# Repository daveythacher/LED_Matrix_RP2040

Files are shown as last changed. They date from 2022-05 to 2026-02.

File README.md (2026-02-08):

# LED_Matrix_RP2040
Hardware module for abstracting LED matrix interface. Raw data is sent over an IO bus which is then replayed to the LED matrix repeatedly. Application logic is responsible for producing raw data and generating synchronization signal.

## Status
This code base is a work in progress. See [this](https://github.com/daveythacher/LED_Matrix_RP2040/blob/main/LED_Matrix/README.md#status) for more details.

This code basis will likely be abandoned due to integrity issues. Most LED Matrix libraries have issues with integrity. I have been on an adventure trying to improve the quality of LED Matrix displays, which is quite poor in my opinion. Only some of my findings have been documented and at some point I will just have to be comfortable with the journey's merit. (I trust my verbage finds you even better.) My personal growth from this has been a unique perspective on reality, which was certainly worth my time.

Roadblock: [Issue Number 61](https://github.com/daveythacher/LED_Matrix_RP2040/issues/61)

I assume no liability in any way as a result of this code base. This code base is [licensed under GPL 3](https://github.com/daveythacher/LED_Matrix_RP2040/blob/main/LICENSE).

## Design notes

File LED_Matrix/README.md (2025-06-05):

# Internal Documentation
Place to talk about internal code stuff.

## Overview
This code base is divided into two main parts: matrix/multiplex and interface. Not all features are implemented in this code base.

## Status
### Matrix:
PWM - experimental

SPWM - experimental

### Multiplex:
Decoder - experimental

### Interface/Node:
UART - experimental

### Interface/Protoocl
Serial - experimental

## List of things:
Planned things:
- 4-bit LUT to accelerate computation. (Moved to application code.)
- TCAM to speed up processing/filtering. (Simplified form used.)
- Portable SIMD operations using standard ALU. (Moved to application code.)
- Pointers/structures to accelerate computation. (Somewhat used.)
- Wrapper to promote in-order execution. (Not really required.)
- DMA wrapper to scope system networking. (Logic not large enough for system service.)
- Watchdog service to failsafe RTOS. (Simplified form used.)
- Tone to detect errors and possibly correct them. (High framerate with acknowledge reduced the value of this.)
- Multiple copies of bits to enable voting. (High framerate with acknowledge reduced the value of this.)
- Implementing data chunks with checksum below protocol. (Hardware flow control reduced the value of this.) 
- Commands and queries for remote control. (Implemented)
- Synchronous trigger for frame swap and refresh sync. (Implemented)
- Concurrent libraries for frame, mutex, queue, threads (RTOS), atomic, etc. (Simplification reduced the value of this.)
- Shift register based vector or ring buffer. (Somewhat used.)
- S-PWM algorithm using universal table for increasing color depth. (Moved to application logic.)

Other things:
- Hardware interface logic vs high level software (asynchronous vs dependency order) portability. (File approach used.)
- Preprocessor vs linker symbol management vs dynamic runtime. (Preprocessor used.)
- RAM vs XIP caching. (Copy to RAM used.)
- ASM vs C vs C++ (C++ where possible.)

Moved to application:
- Dot correction computation
- Brightness compuation
- Gamma computation
- Color depth computation
- Color order computation
- Mapping computation

IO protocol properties:
- Event loop
- Flow control
- Error protocol
- Priority regulation
- Addresssing
- Reliability
- Error correction and detection
- Latency regulation
- Duplex
- Framing
- Topology

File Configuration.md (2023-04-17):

# Configuration
## name 
This is the name given to the configuration and corresponding binary. Note binary will have the following prefix: led_

This name must be different from the algorithm. Currently this means something other than the following: BCM, PWM and TLC5958

## enable 
This must be true or false. If false this build will not be included in the build script.

## app
This is a string for the corresponding application in src folder. These applications determine the serial implementation protocol. (None have been tested!)

## algorithm
This is the name of the LED panel driver or algorithm used to talk to the panel. Note some drivers from Macroblock, ChipOne, etc. are not fully documented and are suspected of having a NDA. This project does not plan to use any information violating such agreeements. (Note the modular nature of this could allow dissemination without such information.)

GEN 1 panels (standard panels) currently use ON/OFF (ON_OFF), BCM or PWM. (Traditional PWM works better with FPGA, but this is not supported by this code base.) These generally require a tradeoff in quality, refresh and/or density.

GEN 2 panels (hardware PWM panels without memory) can only be TLC5946 (incomplete) currently. These allow higher refresh rates at high quality.

GEN 3 panels (hardware PWM panels with memory) can only be TLC5958 (incomplete) currently. These allow higher densities (larger panels) at high refresh and quality.

## fps
This is the number of FPS desired by GEN 3 panels. This is used to verify the serial clock requirements.

## multiplex
This is the scan number marked on the back of the panel. This number is usually in the middle near a S prefix.

## multiplex_name
This is the name for multiplexing approach used. Currently available are Direct and Decoder. Direct is more common in low multiplex.

## max_rgb_led_steps
This is the number of uA's supported by the LEDs without multiplexing. (This is generally something along order of 2000-8000.) Assuming the LED is capable of lighting up slightly at 2uA and the min constant forward current of the red, green and blue colors is 8mA. You should have 4000 steps or support around 12 bits of PWM if the panel was single scan.(8mA / 2uA = 4000) This is believed to be the contrast ratio of the LEDs, which determines aspects of the quality/dynamic range. (Mapping function/table and dot correct are important for ensuring color accuracy.)

The library will determine the max number of PWM bits from this number. By dividing this number by the multiplex and taking the log2 of the result. Note if you lower the forward current you should change this value to avoid wasting serial bandwidth and memory. The compiler will check for errors if this is set to an unsupported value. There is only so much memory on the RP2040, so lowering this may be required. This lowers the color depth on the device. Note this number should be whole numbers only.

Not used by ON_OFF.

## max_refresh
This number is the refresh rate in Hz of the panels multiplexing. When using BCM this will override the FPS. Note this number should be whole numbers only.

## columns
This is the number of real columns in the panel. Not the number of columns you see in the panel. If you have 16x32 with 4 scan panel you will need to set this to 64. panel_rows / (2 * scan) * panel_columns. Mapping of pixel location is not handled by the RP2040, this should be done in application logic or by logic driving serial bus. Note this number should be whole numbers only.

## serial_clock
This is the target serial bandwidth, in MHz. This is used by the compiler to verify the timing. This should not exceed 25MHz for most panels. Note you may wish to lower this is in some cases to meet timing and/or promote signal stability. (Measure rise/fall time, hold time, etc.) Note this number can have decimals.

## blank_time
This is the number of uS the LEDs will be off during multplexing to prevent ghosting. This is usually 1-4uS. Note this number should be whole numbers only.

## red_gain
Constant current gain value for Red LED. This value is constant multiple of the default gain. 1.0 configures the gain to be the default gain. Note this number can have decimals. (Only used/needed by TLC5958.)

## green_gain
Constant current gain value for Green LED. This value is constant multiple of the default gain. 1.0 configures the gain to be the default gain. Note this number can have decimals. (Only used/needed by TLC5958.)

## blue_gain
Constant current gain value for Blue LED. This value is constant multiple of the default gain. 1.0 configures the gain to be the default gain. Note this number can have decimals. (Only used/needed by TLC5958.)

# Timing Formulas:

## Timing algorithm for BCM: (Note blanking time may reduce refresh.)

serial_clock / (multiplex * columns * max_refresh * 2^round(log2(max_rgb_led_steps / multiplex))) >= 1.0

## Timing algorithm for PWM: (Note blanking time may reduce refresh.)

serial_clock / (multiplex * columns * max_refresh * 2^(round(log2(max_rgb_led_steps / multiplex)) + 1)) >= 1.0

## Timing algorithm for ON_OFF: (Note blanking time may reduce refresh.)

serial_clock / (multiplex * columns * max_refresh * 2) >= 1.0

## Timing algorithm for TLC5946: - WIP  (Note blanking time may reduce refresh.)

serial_clock / (multiplex * columns * max_refresh * 12) >= 1.0

serial_clock / (multiplex * max_refresh * 2^round(log2(max_rgb_led_steps / multiplex))) >= 1.0

## Timing algorithm for TLC5958: - WIP (Note blanking time may reduce refresh.)

(serial_clock * 0.75) / (multiplex * columns * fps * 16 * 3) >= 1.0

serial_clock / (multiplex * max_refresh * 2^max(round(log2(max_rgb_led_steps / multiplex)), seg_bits)) >= 1.0

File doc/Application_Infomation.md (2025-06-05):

# Application Information
Section documenting various application information.

### Size
TODO:

#### Fan out
TODO:

### Refresh
TODO:

### S-PWM
TODO:

### Ghosting
TODO:

## Mappers
All of this is handled by application logic.

### Color Temperature (Gamma)
Note all color mapping is handled via application logic.

### Dot Correction
Dot correction used to adjust for slight imperfections in LEDs, LED drivers, etc. is handled by application logic.

### Multiplexer
Pixel locations within panels is handled by application logic.

### Pixel
Panels mappings and orrientation of panels is handled by application logic. 

### RGB locations
Color locations within pixels is handled by application logic.

### Brightness
Handled by application logic.

### Color Depth
TODO:

## Power supply
It is important to use a quality power supply with proper voltage rating, load regulation, current capacity, power supply response time, etc.

## Wiring and Signal issues
TODO:

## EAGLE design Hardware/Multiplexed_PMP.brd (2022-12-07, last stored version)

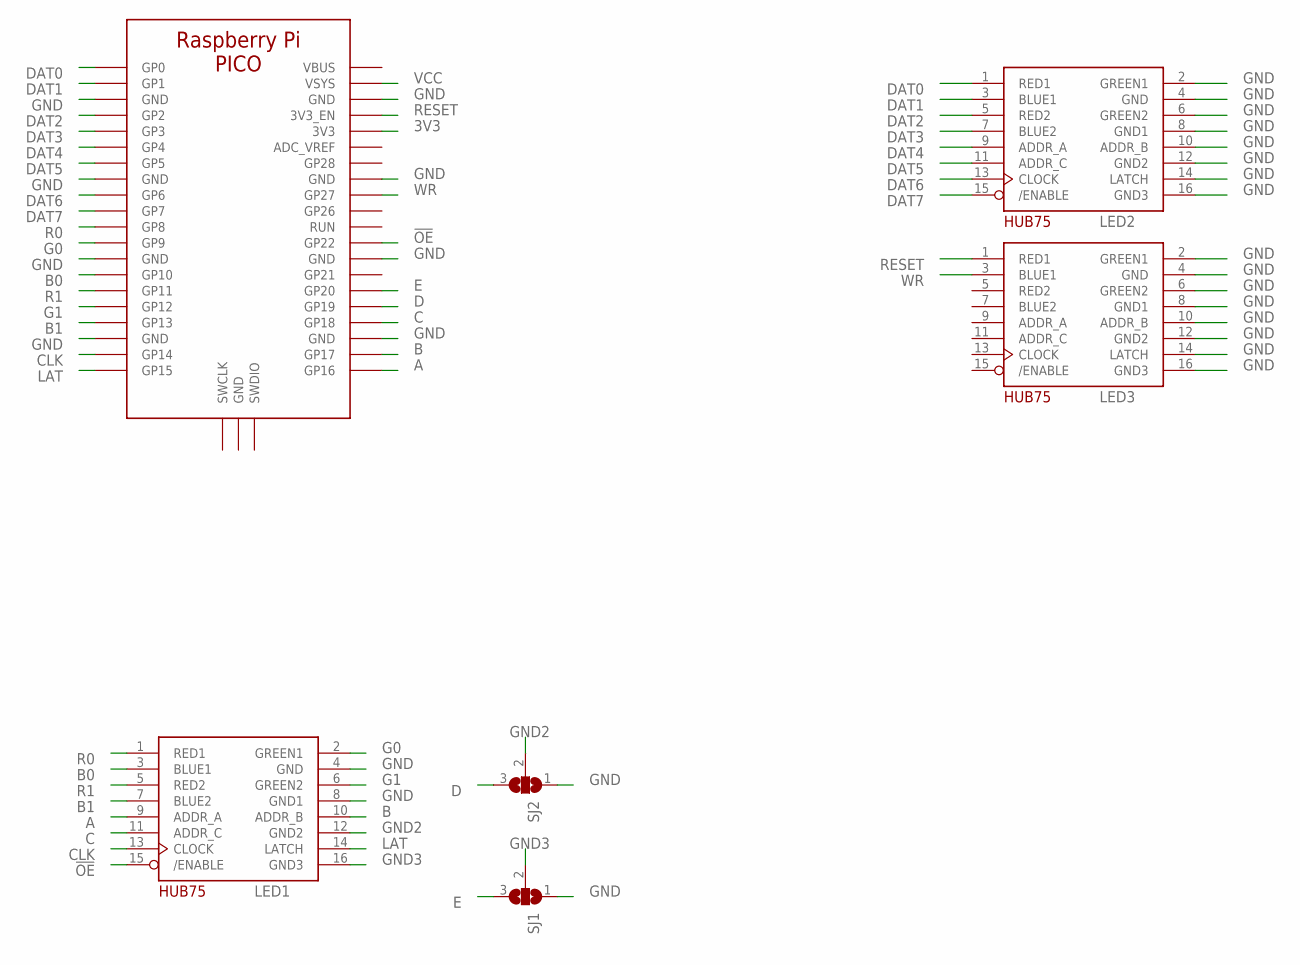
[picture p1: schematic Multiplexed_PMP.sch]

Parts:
LED1, LED2, LED3: HUB75MATRIX; 2X08-IDC
SJ1, SJ2: SJ2W; SJ_2
U$1: PICO

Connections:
3V3: U$1.P$3V3 (3V3)
!OE: LED1.15 (/ENABLE), U$1.P$GP22 (GP22)
A: LED1.9 (ADDR_A), U$1.P$GP16 (GP16)
ADC_VREF: U$1.P$ADC_VREF (ADC_VREF)
B: LED1.10 (ADDR_B), U$1.P$GP17 (GP17)
B0: LED1.3 (BLUE1), U$1.P$GP10 (GP10)
B1: LED1.7 (BLUE2), U$1.P$GP13 (GP13)
C: LED1.11 (ADDR_C), U$1.P$GP18 (GP18)
CLK: LED1.13 (CLOCK), U$1.P$GP14 (GP14)
D: SJ2.3, U$1.P$GP19 (GP19)
DAT0: LED2.1 (RED1), U$1.P$GP0 (GP0)
DAT1: LED2.3 (BLUE1), U$1.P$GP1 (GP1)
DAT2: LED2.5 (RED2), U$1.P$GP2 (GP2)
DAT3: LED2.7 (BLUE2), U$1.P$GP3 (GP3)
DAT4: LED2.9 (ADDR_A), U$1.P$GP4 (GP4)
DAT5: LED2.11 (ADDR_C), U$1.P$GP5 (GP5)
DAT6: LED2.13 (CLOCK), U$1.P$GP6 (GP6)
DAT7: LED2.15 (/ENABLE), U$1.P$GP7 (GP7)
E: SJ1.3, U$1.P$GP20 (GP20)
G0: LED1.2 (GREEN1), U$1.P$GP9 (GP9)
G1: LED1.6 (GREEN2), U$1.P$GP12 (GP12)
GND: LED1.4 (GND), LED1.8 (GND1), LED2.2 (GREEN1), LED2.4 (GND), LED2.6 (GREEN2), LED2.8 (GND1), LED2.10 (ADDR_B), LED2.12 (GND2), LED2.14 (LATCH), LED2.16 (GND3), LED3.2 (GREEN1), LED3.4 (GND), LED3.6 (GREEN2), LED3.8 (GND1), LED3.10 (ADDR_B), LED3.12 (GND2), LED3.14 (LATCH), LED3.16 (GND3), SJ1.1, SJ2.1, U$1.P$GND (GND), U$1.P$GND3 (GND), U$1.P$GND8 (GND), U$1.P$GND13 (GND), U$1.P$GND18 (GND), U$1.P$GND23 (GND), U$1.P$GND28 (GND), U$1.P$GND33 (GND), U$1.P$GND38 (GND)
GND2: LED1.12 (GND2), SJ2.2
GND3: LED1.16 (GND3), SJ1.2
LAT: LED1.14 (LATCH), U$1.P$GP15 (GP15)
R0: LED1.1 (RED1), U$1.P$GP8 (GP8)
R1: LED1.5 (RED2), U$1.P$GP11 (GP11)
RESET: LED3.1 (RED1), U$1.P$3V3_EN (3V3_EN)
VBUS: U$1.P$VBUS (VBUS)
VCC: U$1.P$VSYNC (VSYS)
WR: LED3.3 (BLUE1), U$1.P$GP27 (GP27)

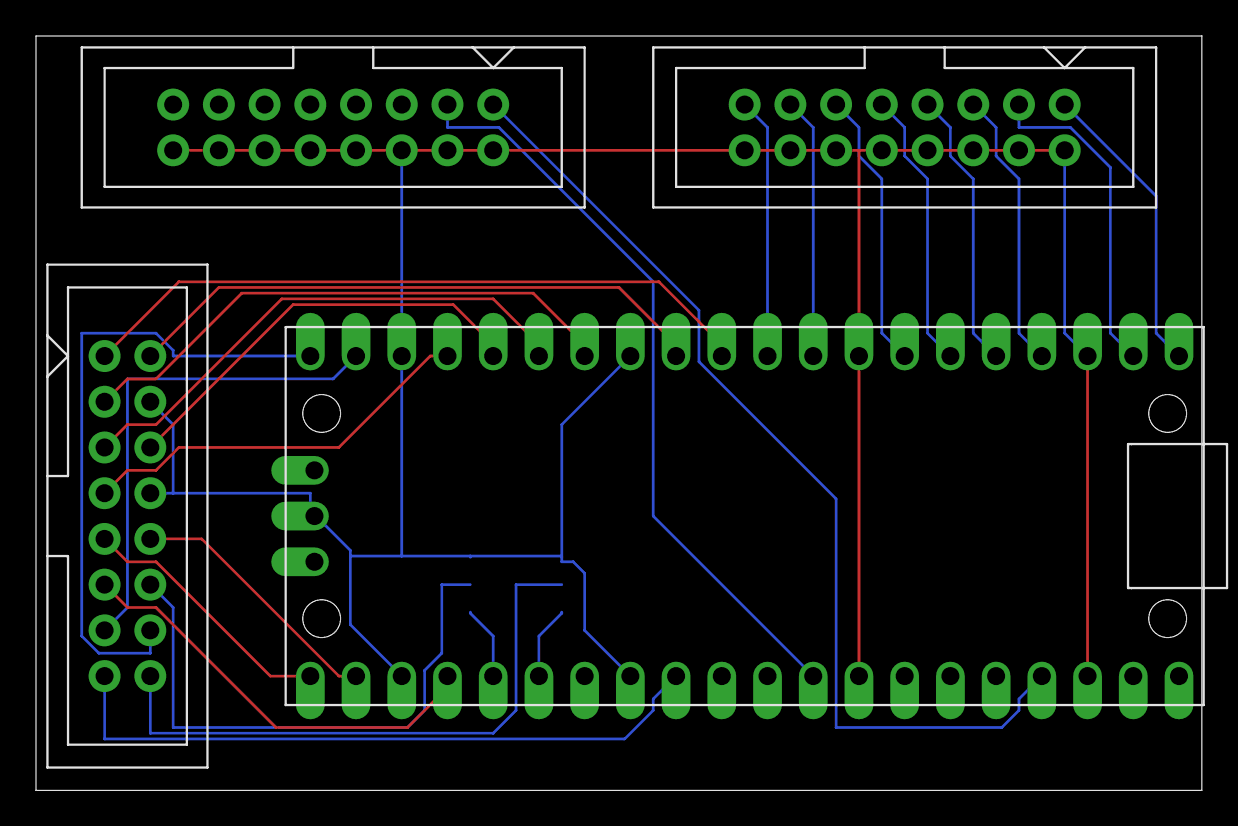
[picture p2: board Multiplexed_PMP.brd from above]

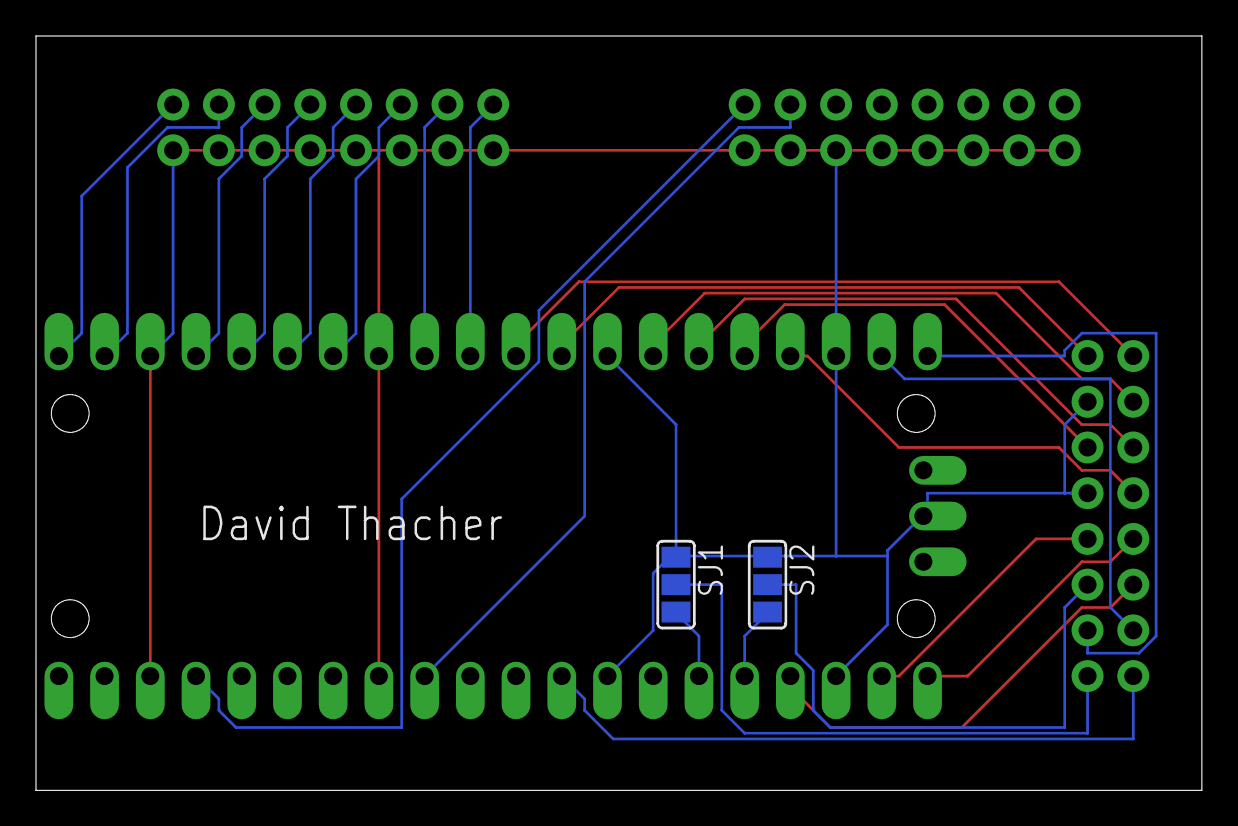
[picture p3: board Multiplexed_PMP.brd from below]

Board: 2 copper layers, 64.8 x 41.9 mm, 6 parts (2 on the bottom side), 27 nets.

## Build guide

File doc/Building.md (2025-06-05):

# Building
## Setup
### Installing prereqs
See scripts/Linux
### Installing submodules
See LED_Matrix/lib
## Building firmware:
### Building with CMake
```bash
mkdir LED_Matrix/build
cd LED_Matrix/build
cmake .. -DPICO_SDK_PATH=../lib/external/pico-sdk
make -j 16
```

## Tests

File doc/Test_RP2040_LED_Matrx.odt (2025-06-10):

Conditions:

Matrix is configured for two RGB chains, except where mentioned otherwise.

Firmware is configured with the following settings:

- Number of steps is 16.
- Number of columns is 8.
- Number of scans is 4.
- Baud rate 7.8MBaud.
- PWM Algorithm using BUS8.
- Decoder Multiplexer using BUS8.
- UART Node using Serial Protocol.
- UART flow control enabled.

Chapter 1: Logic

Section 1: Verify PMP PIO:

Case 1: Verify clock is 8.33MHz.

Case 2: Verify clock wave form is square with 8 loads.

Case 3: Verify clock remains constantly on.

Case 4: Verify all PWM periods are present plus null period.

Case 5: Verify LAT is one clock pulse.

Section 2: Verify Multiplexer PIO

Case 1: Verify refresh is at least 3kHz.

Case 2: Verify proper progress from A, B and C of decoder.

Case 3: Verify all 8 scans are present.

Case 4: Multiplexing is only started after null period.

Case 5: Verify OE is high only for blank time.

Section 3: Verify Ghost PIO

Case 1: Verify LEDs discharge (turn on) within one GCLK period.

Case 2: Verify LEDs charge (turn off) within one GCLK period.

Case 3: Verify blank time is 10uS.

Case 4: Verify brightness is at least 60 percent.

Case 5: Verify PMOS capacitors charge and discharge within blank time.

Case 6: Verify multiplexing has completed within blank time.

Section 4: Multiplexer

Case 1: Verify frame transition is synced to FCLK.

Case 2: Verify frame transition is within on refresh.

Case 3: Verify frame transition is only at the top of a scan.

Case 4: Verify FCLK on time a quarter of the frame time.

Section 5: Interface

Case 1: Verify swap command acknowledged before FCLK.

Case 2: Frames are retained till another frames arrives.

Case 3: Verify flow control signals respond.

Chapter 2: Timing

Section 1: Verify BUS8

Case 1: All data pins are setup at least 5nS before clock edge.

Case 2: All data pins are held for at least 5nS after clock edge.

Case 3: Clock is stopped for LAT signal.

Case 4: Verify OE on or off time is never shorter than 200nS.

Case 5: LAT arrives after last data shift.

Case 6: LAT pin rises 20nS after clock period.

Case 7: LAT pin is held for 10nS.

Section 2: RP2040 processing

Case 1: Verify multiplexing is never slowed by frame swap or data operations.

Case 2: Verify data is consumed faster than data rate.

Case 3: Verify processing frame rate exceeds 240 FPS.

Chapter 3: Power

Section 1: Voltage

Case 1: Verify the voltage to the LED driver is 3.3V +/- 0.1V under max and min load.

Case 2: Verify the voltage to the LEDs is 5V +/- 0.01V under max and min load.

Section 2: Current

Case 1: Verify current response time is 10kHz or higher.

Case 2: Verify decoupling of LED drivers and LEDs.

Case 3: Verify RP2040 subsystem draws no more than 60mA.

Case 4: Verify LED drivers are accurate to +/- 3 percent between any channel.

Case 5: Verify a pixel of up to three colors draws no more than 30mA.

Section 3: Module

Case 1: Dedicated power conversion from 12V to 5V is available.

Case 2: Dedicated power conversion from 5V to 3.3V is available.

Chapter 4: EMI

Section 1: Interface

Case 1: Verify balanced differential signals.

Case 2: Galvanic isolation is used.

Section 2: Power

Case 1: Chokes are used on 12V line.

Case 2: Ground power is stable.

Chapter 5: Commands

Section 1: Data command

Section 2: Test command

Section 3: Power command

Section 4: Swap command

Section 5: Reboot command

Chapter 6: Protocol

Chapter 7: Node

Section 1: UART

Case 1: Verify flow control.

Case 2: Verify max baud.

Case 3: Verify start, stop, 8 bits, parity none.

Chapter 8: Watchdog

Chapter 9: Bootloader

Chapter 10: LED driver detection

Chapter 11: Thermal

Section 1: LED drivers

Section 2: Environment

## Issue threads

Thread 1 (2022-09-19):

Add support for traditional PWM for small panels.

daveythacher, 2022-09-19:
Add support for traditional PWM for small panels with reduced color depth. Panels smaller than 32x32 with no more than 10-bit contrast in single scan.

daveythacher, 2022-09-19:
This is possible because of the RP2040's CPU enabling processing on the panel. Sending bit planes would consume too much bandwidth for traditional PWM. Using BCM would save bandwidth, but in certain cases BCM is not recommended. The difference is (2^x)/x.

daveythacher, 2022-09-29:
This is mostly in there. No testing done, but the concept is there. The CPU is likely stressed more with this approach, I have not fully tested the exact limits. May just close this out without it.

Simple change since BCM was already using traditional PWM period. The operation is like BCM, the lower (1 << PWM_bits) - 1 bitplanes are sent while the last one is zero. The only difference is increase computation and memory consumption for one rising edge per period. This should help with duty cycle or brightness on displays with a small amount of capacitance on the column traces.

There is probably not enough memory or computaton in the RP2040 for scrambled PWM and because of this the frame latency should always be good. (Serial bandwidth divided by memory means good frame latency.) Note the point of this change is to reduce rising edges, which scrambled PWM would increase. Therefore I cannot justify adding scrambled PWM on this device. This can be found on GEN 2 and GEN 3 drivers, support will be there instead of GEN 1. GEN 2 can only use it in low multiplex.

Serial interface targets a FPS of 30, which is plenty for 100Hz min refresh. The traditional PWM/BCM syncs on 10mS edges while frames arrive on 33mS edges. Scrambled PWM is not required. If we were doing 60-120 FPS this would be worth it. Again UART and CPU may not be rated for this in an economical way. This project does scale well beyond certain displays and the RP2040 is the only reason this many features exist at this price point.

daveythacher, 2022-09-29:
Scrambled-PWM makes sense for hardware. Larger notions of PWM bits aka GEN 2 and GEN 3 panels. It allows you to escape the GCLK sequence. Then come back later on. VSYNC is global reset command. So the prediction of this is an increase in refresh rate.

It is used to promote a single data unit with variable PWM bits using the same hardware. GEN 1 does this in software so there is no real need. S-PWM is for hardware PWM.

Closed 2022-09-29.

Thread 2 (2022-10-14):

Add support for LED drivers with upper and/or lower ghosting

daveythacher, 2022-10-14:
In order to support higher refresh rate you need to use LED drivers with ghosting logic. This may not work with the existing logic. However is probably easy to integrate.

These are required due to parasitic capacitance in LED Matrix which cause the LEDs to light slight for brief periods of time in a manner which is undesired. Current flows through the LEDs into the capacitors during charge of the capacitors. This stops when the capacitor reaches a voltage which blocks the LED from having enough forward voltage to allow enough forward current to light the LEDs. The solution to this is, is to charge the capacitors from the low side.

The high side may also have some capacitance which could cause problems during row changes. This is generally fixed by using pull down resistors and blanking time. This function should mostly be supported already. This feature needs low side drivers to be meaningful. The low side will block all the LEDs from lighting while the high side capacitors discharge, allowing the display to be completely off.

Note without these the max refresh rate is usually something like 240Hz. Most other code bases are only capable of this. Drivers which are believed to be accessible supporting this are TI drivers and MBI5124.

daveythacher, 2022-10-14:
This is feature will be used to build custom panels without the use of hardware PWM LED drivers. This should allow the refresh rate to be 1-2kHz. This is a somewhat pricey way to go, however it avoids NDA and Ti components are expensive.

It is potentially possible to get this working using pull up and pull down resistors using standard constant current shift registers or basic shift registers. However this has not be fully explored. This would enable just about anyone to build a high refresh LED display on PoE. However the power loss and cost have not been factored in. Timing performance is casually assumed to be trivial.

daveythacher, 2022-11-07:
Note you need around 3kHz for this to be flicker free. This is required due to multiplexing and there is nothing you can really do about it. This can be done on pre-made panels in many cases but requires lowering the color depth and possibly chain length. Note as the refresh rate increases ghosting generally becomes more observable and blanking time is required to allow the RC times to pass.

Anti-ghosting technology without discrete blanking signal will need to use S-PWM. Analog dot correct may not be required however dot correct is likely required as part of this. See issue #6 and #7 for more details.

Anti-ghosting technology can be added without special logic. On the high side, assuming PMOS drivers, you will need a pull down capable of draining the parasitic capacitance. On the low side you will need a pull up capable of charging the parasitic capacitance. For highest power efficiency these will need to be dis-connectable. For quickest RC times these may wish to have low resistance values. Note low resistance may result in EMI. Using 10k resistors may provide low cost options, but may struggle with RC times.

Note the high side drivers, assuming PMOS, should be low resistance for the sake of color consistency if not using constant current drivers. This can save cost but may result in less color accuracy and consistency. Dot correct would be required to manage this. It is believed this can be done using digital control. If the dot correction values range from 0.5 to 1.0 of the current limit. (Using fixed point math.) Increasing the number of bit should allow granularity required. This will increase the number of PWM bits potentially significantly or by only a single bit.

Careful observation of the PWM period time is required for flicker free using high refresh rate. The whole period time must be present. There is an interesting trick of zeroing out some of the BCM shifts, however I am not sure BCM is recommended at higher refresh rates. This puts more stress on the controller. However for some applications the RP2040 is capable.

daveythacher, 2022-11-07:
In order to support non-hardware PWM drivers, I will need to create custom panels using 2 HUB75 connectors. Each responsible for a 16x8 section of a 16x16 module. This complicates the code somewhat and I am still considering this.

daveythacher, 2022-11-07:
> In order to support non-hardware PWM drivers, I will need to create custom panels using 2 HUB75 connectors. Each responsible for a 16x8 section of a 16x16 module. This complicates the code somewhat and I am still considering this.

Non-hardware PWM drivers are painful. They require so much IO. Before the RP2040, the only known configuration capable of flicker free is with a FPGA. The RPI PICO module is well under the cost of a MCU and FPGA combination. This combination is also believed to support the required power efficiency for supporting control logic plus microprocessor within 15 W (PoE) power budget.

There may be a way for the MCU and FPGA combination or using the FPGA alone to break even with multiple RPI PICO modules. However this may have EMI and signaling issues. The complexity of code support is not as good with HDL as it is with C/C++. Non-hardware PWM drivers also require a lot of data movement which may complicate things in other ways also. (Was able to avoid this in smaller scale conceptual experiments. However this is to be taken with a grain of salt.)

FPGA was previously believed to be the only means of getting traditional PWM instead of BCM. However the RP2040 is capable using software tricks to achieve this in small sections. This is believed to require decent memory performance.

daveythacher, 2022-11-15:
1.25kHz is the min frequency recommendation for low flicker. At 3kHz it is assumed that no flicker will occur. Cameras may still see this multiplexing however there should be minimal flicker from the panel if the frequency is this fast.

daveythacher, 2023-04-13:
Relates to #14, #15 #16, #17 and #22

Closed 2023-05-24.

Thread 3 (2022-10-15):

Consider removing special LED drivers

daveythacher, 2022-10-15:
Consider removing special LED drivers like TLC5958, MBI5153, etc. These may not be required and may not be available.

daveythacher, 2022-10-16:
I am not going to remove these. This project has two sections a front end protocol and a back end control logic implementation. The design of this module is to provide a translation for abstracting the complexity of different back ends. Many configurations are possible. Most if not all of the settings will be handled by the RP2040 firmware outside the knowledge of the user. However some details will likely need exist such as pixel mapping, brightness, gamma correction, etc. These will likely not exist in the module or will use the front end protocol to configure the back end.

At some point it may be worthwhile to make the mapping functions change via the front end protocol. This would move all the gamma correction and brightness logic out of the firmware. Allowing this to be updated by the application logic like pixel mapping is. Thus allowing the firmware to focus on control.

The purpose of this module is to allow cleaner interface and remove the concern for things like electrical signals.

daveythacher, 2022-10-16:
This approach is expensive. It plays nice with SoCs, MCUs, etc. However it does not scale well. The power consumption of this can be better than a receiver card which is a bigger, cheaper notion than this.

This module has the potential to remove driver type, refresh, color depth, etc. from the programmer. A simple panel module datasheet would disclose what is supported by this module/panel. Different vendors could use different front end protocols. Every panel module could use a different back end implementation if desired.

Closed 2022-10-16.

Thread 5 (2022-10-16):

Make index_table reprogrammable by application logic

daveythacher, 2022-10-16:
As mentioned in #3 it would be better to make the index_table capable of being changed. This is allowed in receiver cards. This would allow gamma, brightness, CIE1931, etc. to be handled in application logic. This will be handled differently for each front end protocol. Note the application logic will need to be aware of how many PWM bits are used by the firmware. This value should never change for firmware as it comes from the panel which is reflected in the firmware.

Reworking the RGB sequence is also possible in the application logic. These features are similar to how the RPI RGB LED Matrix handles things. However they are probably closer to the receiver cards implementation.

Note I am not sure if LED driver configuration settings should be exposed to the application protocol. Rather I am thinking it should be left to the module via static compilation.

Certain versions of the firmware may need to be closed source for NDA purposes. The others can be open source and therefore changed. More than likely the only supported platforms would be open source due to the reverse engineering of RP2040 firmware. This for hobby purposes and I am not sure how successful this would be for commercial products. Receiver cards are more economical. However this could be more beginner friendly.

It would be nice to have access to MBI5153 without so many complications. Receiver cards have access however the power consumption and legality is somewhat problematic. Hardware PWM firmware for receiver cards appear to need specific Ethernet requirements also.

daveythacher, 2022-10-16:
Closing this out. Changes were quick and dirty. Created new type called packet, which will likely need some adjustments later on. This defines the protocol for CDC and UART. This is defined in Matrix/matrix.h which is not a good place for it. However will worry with this later on.

Closed 2022-10-16.

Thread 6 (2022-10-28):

Add dot correct

daveythacher, 2022-10-28:
Dot correction logic is used to level the brightness between pixels in rows and columns. This feature may wish to be dropped in some cases, so build logic may be required.

daveythacher, 2022-11-07:
This could be done easily for hardware PWM LED drivers/panels however there is likely not enough RAM for non-hardware PWM LED drivers/panels. Therefore I am thinking it would be better to proceed using the application to process this. See #7

Closed 2022-11-07.

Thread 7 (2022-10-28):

Make input format RGB-48

daveythacher, 2022-10-28:
Remove all scaling and looks up from code. Make serial protocol use RGB-48. GEN 1 will scale this down to RGB-24 using linear. GEN 1 will still use index_table to convert RGB-24 values to bitplanes. However this table cannot be changed as this would be pointless.

Application logic will do all scaling into RGB-48 bit value. If the application logic wish to only use RGB-24 for GEN 1, it should scale it to RGB-48 before hand.

Application logic is responsible for ensuring the following:
- Dot correct
- Flicker free
- Required scaling (S-PWM/multiplex)
- Brightness
- CIE1931
- Gamma

This will remove the processing logic from the RP2040, which is kind of sad. However the other core can be repurposed to protocol logic. GEN 1 will still consume a decent amount of computation doing look ups. In theory these look ups could handle this, however the memory size is too large.

This limit exists because of dot correct. Dot correct pretty much requires a microprocessor. However there are other options.

daveythacher, 2022-10-28:
New protocol: (Work in progress)
```
60kB line buffer (RGB-48 format)
	10240 pixels per multiplex
	Max of 327680 pixels
2 line buffers required
	120kB of RAM required
```

daveythacher, 2022-11-15:
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

This will need to be reconsidered in another issue. This is for GEN 2 and GEN 3 drivers. TLC5958 currently does not support this and is untested/unfinished.

daveythacher, 2022-11-15:
Note GEN 2 and 3 do not use index_table translation. The 16 bit values are transferred directly out via PIO shifter. So this is much faster.

GEN 1 uses index_table in BCM and PWM to create bit planes for PIO. Performance of this should be fairly good as it works off a look up table. This reduces some of the computation. PWM is mostly bound by RAM and IO. BCM is not recommended at high frequency and the computation there is a little faster. Which may compensate for the RAM reduction.

The RP2040 has good locality which enables the PWM implementation to work.

daveythacher, 2023-05-26:
I took this out after and may need to go back in. So re-opening.

daveythacher, 2023-05-28:
There is a trade off here. If you use RGB-24 we can support high density GEN 3 with higher pixel counts. (Up to 64x128 potentially.) However if you use RGB-48 you can support higher color depth a lower multiplexes. The issue is the RAM usage.

daveythacher, 2023-05-28:
LEDs are only good for about 12 bits or RGB-36. Bytes force us to RGB-24 or RGB-48.

daveythacher, 2023-05-28:
Note with RGB-48 the limit would be 64x64 potentially. So we losing a decent amount of range for 4096 pixels.

I want this to be one or the other. I could make it a parameter, however this would create issues with serial protocol compatibility. My concern for 8192 pixels is the fan out on the GCLK signals. (CLK in this case is likely fine.) Even with TLC5958 which is three times better with fan out compared to MBI5153 (uses modular PCB topology) is how many chips there are. In order to fight this you would be looking at high multiplex to lower the number of chips. It is potentially manageable at that point.

Doubling the pixel count with TLC5958 is probably do able. With MBI5153 it is likely not. The lower the multiplex the worse it gets. Granted GEN 3 is likely only used in high multiplex situations. However this needs to be consistent.

I wonder why they would build a GEN 3 64x128 panel unless it was low refresh. I have a slight preference for high refresh so I am going to consider 64x64 as a good upper limit for the sake of the modular PCB designs. It should be noted however that using TLC5958 at max multiplex is likely within RGB-24 and therefore capable of 64x128.

Closed 2023-05-28.

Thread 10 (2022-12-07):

Switch to windowed serial protocol

daveythacher, 2022-12-07:

daveythacher, 2022-12-07:
This is Serial implementation specific, not an issue. I wasn't thinking.

Closed 2022-12-07.

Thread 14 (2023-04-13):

Test BCM Matrix Algorithm

daveythacher, 2023-04-13:
This was working at one point, however this does not work on the main branch. Update PIO code to use clearer instructions.

daveythacher, 2023-04-13:
Add documentation under LED_Matrix/Lib/Matrix/BCM and LED_Matrix/include/Matrix/BCM

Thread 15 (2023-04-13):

Test PWM Matrix Algorithm

daveythacher, 2023-04-13:
Update PIO code to use clearer instructions.

daveythacher, 2023-04-13:
Add documentation under LED_Matrix/lib/Matrix/PWM and LED_Matrix/include/Matrix/PWM

Closed 2023-04-17.

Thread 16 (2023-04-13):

Test TLC5958 Matrix Algorithm

daveythacher, 2023-04-13:

daveythacher, 2023-04-13:
Add documentation under LED_Matrix/lib/Matrix/TLC5958 and LED_Matrix/include/Matrix/TLC5958

daveythacher, 2023-05-28:
Note this currently only supports half the panel.

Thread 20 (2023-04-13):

Test UART Serial Algorithm

daveythacher, 2023-04-13:

daveythacher, 2023-04-13:
Add documentation under LED_Matrix/lib/Serial/serial_uart, LED_Matrix/src/uart and LED_Matrix/include/Serial/serial_uart.

daveythacher, 2023-05-26:
Create idle loop to fire bus idle token from device to host every 10uS.

Host must send bus active token to device.
Host must wait for the bus to become active (no more idle loop on device). (Timeout of 100uS.)
If error device discards frame and enters idle loop.
If successful device enters idle loop once completed.

Create idle loop within serial_task

If frame does not get response back within timeout host can attempt to recover the bus back to idle.
If host detects the bus became idle too soon, frame is lost and host will drop it. (UDP)
Frame corruption is allowed in this protocol as it is not believed to be worth the computation. (However DMA may support verification.)

This would supersede the serial_uart_v2.
This works to the same goal of marking frames on the wire just without discrete control signals.

daveythacher, 2023-05-26:
I may be interested in replacing the current logic with the previous post's outline. This may also remove the need for the other UART version.

daveythacher, 2023-05-28:
May want to add checksum to this. DMA may be able to do this passively.

daveythacher, 2023-05-29:
May want to remove the callback since this is now an interface library. There is no need for this anymore.

daveythacher, 2023-07-13:
Tested aspects of this.

daveythacher, 2023-07-13:
Tested state machine. (idle and start tokens. Packet length.)
Tested CRC logic calculation.
Did not pass valid data through. Did not test CRC rejection.

daveythacher, 2023-09-19:
Lets go back to framed comms.

daveythacher, 2023-09-20:
One core is pretty much consumed on convert the RGB values into bitplanes to conserve bandwidth. The bandwidth requirement for a single 16x32 display is 31.5Mbps (0.74Mbps for hardware PWM). This is about 512 pixels, with this core we can support something like 8192 pixels.

Another core is pretty much consumed doing multiplexing at high frequency. (This is better with hardware PWM.)

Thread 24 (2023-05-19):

Add Gherkin and/or Jenkins front end for config file generation

daveythacher, 2023-05-19:
The build system is designed to support configuration and build flavors for artifact production.

Currently a groovy script is used to create a bash script which calls CMake. However CMake can be used directly if desired, which should work on any platform.

daveythacher, 2023-05-19:
Rough sample to give idea:
```Gherkin
Given binary named POE
When using serial uart
When using multiplexer Decoder
When using matrix BCM
And multiplex scan 8
And serial clock 15 MHz
And frame rate of 30
And LED contrast of 500
And panel refresh of 500 Hz
And panel with 128 columns
And anti-ghosting blank time of 10 uS
Then build it
```

daveythacher, 2023-05-25:
Thinking this will be done in ruby or maybe Python to create the configuration file. From there the ball can be handed off to groovy.

Cucumber still does not have support on Groovy for the run time it is still Java based with Groovy code support. The same it was 9 years ago...

I remember the Java version worked well, but not what I want for this. Ruby worked very well if you know Ruby. Python was okay, but not as good as Java/Groovy or Ruby. Python is called Lettuce, if I recall correctly. However now they are using Behave as semi-official.

More than likely this will be done in Ruby, which I will need to look into a little. More than likely I only need basic features so this should be straightforward.

daveythacher, 2023-05-25:
Then build it may need some more thought put into it. Current groovy scripts are based on the idea of batch compilation which Gherkin struggled with somewhat as I recall. It was do able however it built more for discrete steps. Gherkin works as documentation very well for discrete steps and gives meaningful updates against each step that way. However if you ever find yourself in a batch compilation role it loses the ability report in a meaningful way.

Output of binaries and the corresponding build logs may be painful. However I think the ruby script could manage this, but this would create coupling of the back end of the build system to the front end. I think this should be avoided. Perhaps a save off command could be given to the groovy script to manage this.

daveythacher, 2023-05-28:
Current logic builds one at a time. Currently logic does not support compiling multiple features, rules, examples, etc. This can likely be worked around using the groovy script directly or moving artifacts.

Note Jenkins has nice Cucumber integrations with artifact publishing. Jenkins however should also support flavors using the groovy logic directly.

daveythacher, 2023-05-28:
I am mostly messing around with this. The point of this is make something a little more helpful compared to the configuration file.

daveythacher, 2023-05-29:
Currently the outputs are in the same location and overwrite each other. For the time being this is likely fine. No issues have been seen with this.

Intermediate configuration files are kept in local directory. Only cfg.xml should be committed.

Documentation of cucumber logic is still required.

Closed 2023-05-30.

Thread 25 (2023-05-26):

Add support for two UART connections

daveythacher, 2023-05-26:
This will require dividing the frame buffer into two sections. I will need to think about this some more later on. This has a few compatibility issues.

daveythacher, 2023-05-26:
The issue I have with this is the 2 to 1 relationship of this. I would need to create a background thread that submits the front buffer or build a command protocol. The background thread would create tearing. The command protocol creates blocking and forces reliable transportation without tearing.

I would end up with two serial algorithms running as coroutines. This would also mean more interrupts. I may also have to change the interface to the matrix algorithms.

I think the serial algorithms should stay monolithic. Faster IO protocols are possible with PIO, however this will require an external bridge. This may be pointless, however this may be the cleanest way to go.

Unless I implement a bonded mode. I think I could use pointers to keep this clean with the existing APIs. In fact I may be able to make this approach work with the new version of the serial algorithm I am considering. The only difference is there will be second channel with frame data. If I keep them monolithic then one governs the other. The host will have to obey this.

daveythacher, 2023-05-26:
Note the protocol in #20 is somewhat blocking and does not work with out of order frames. In fact it actually intentionally blocks the problem by allowing only one frame to be in flight. The RP2040 does not have the memory for this, even if it wanted to try this with buffers. This would be closer to USB than Ethernet. This would be like a hybrid of bulk and isochronous? I am not sure TCP or bulk is what I am looking for here.

daveythacher, 2023-05-28:
This may not be required anymore due to #7. Trying to decide if it is worth the complexity.

daveythacher, 2023-05-28:
Decided to remove.

Closed 2023-05-28.

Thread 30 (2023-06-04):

Add support for pull down resistors in P6 panels using MBI5124

daveythacher, 2023-06-04:
Creating issue different from #2, which technically was for low side only algorithm mentioned in documentation and experimental drivers TLC5958 and TLC5946.

daveythacher, 2023-06-04:
After thinking about this some it was discovered that previous experiments likely failed to consider upper and lower blanking time independently. Currently there is only support for lower blanking, which does not work in all cases even with MBI5124 which did show impressive performance.

The preferred solution is upper and lower anti-ghosting hardware which was shown in a MBI5153 panel using ColorLight NetCard to work impressively. However gaining support for that in this project has been found to be difficult without possible legal issues. GEN 1 panels are somewhat preferred due less risk of patent infringement.

In any case this issue needs to create upper and lower blanking. These need to be tested. If they pass this new algorithm needs to be applied to BCM, PWM and ON/OFF matrix algorithms. I am not sure what this means for TLC5958 and TLC5946. Documentation needs to be updated.

daveythacher, 2023-06-04:
You know if you think about it things get crazy. The upper side has a load of 192 units while the lower only has 8 units of load. (Assuming 8 scan 16x32 LED panel.) That PMOS driver is loaded down with a decent size capacitor.

The resistor is constant power loss which is stinks. (Small compared to LEDs.) That resistor effects time constant for multiplexing. It effectively creates low pass filter. This frequency is divided by scan to yield max refresh in theory.

Its crazy that the solution to this is potentially to just shift out zeros then wait. That is pretty straight forward. The other thing that is somewhat interesting is that most latch lines can be done with chip select if they have edge detectors. (Does not work with enable load aka latches.)

daveythacher, 2023-06-04:
Funny thing is the OE line is not used...so there is no low side with the current logic.

Current logic does both in parallel. It changes the row early enough that the same timer should work for upper and lower. Thus there is nothing really to change here. Try larger values of blanking to see if it improves things. (This is not free as it can hurt refresh rates beyond configuration as mentioned in documentation.)

I did correct the low side issue.

Closed 2023-06-04.

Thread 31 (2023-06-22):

Add test drivers

daveythacher, 2023-06-22:
Create serial algorithm which is a test module for matrix algorithms. Create matrix algorithm which is a test module for serial algorithms.

Remove test_driver from serial_uart.

daveythacher, 2023-06-22:
Matrix algorithm should output contents received from serial implementation to UART or USB console.

daveythacher, 2023-06-24:
Create offload test sample for worker.

daveythacher, 2023-06-25:
Need to finish Test Matrix algorithm also.

daveythacher, 2023-06-25:
> Create offload test sample for worker.

Going to hold off on this for right now. Can be done outside of repo anyhow. May not belong in repo.

Closed 2023-06-26.

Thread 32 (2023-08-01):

Test compiling on Windows

daveythacher, 2023-08-01:
Some logic exists for compiling on Windows. However there was an issue with nmake and I stopped after that.

Removed the if successful print output directory contents. This may be left out or ported later on.

daveythacher, 2023-08-01:
Use Raspberry Pi Installer for RP2040. Need to install Java and Groovy. Setup is required with environmental variables.

Closed 2023-08-01.

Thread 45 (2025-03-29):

Remove the external notion PWM bits

daveythacher, 2025-03-29:
- Switch to ON/OFF RGB.
- Change serial protocol type to two pixels per byte. This will conserve bandwidth.
- Move the dot correction function to an internal notion.

daveythacher, 2025-03-29:
Allow three serial protocol types:
- Two pixels per byte (3bpp - Up to 32 scan)
- One pixel per byte (6bpp - Up to 8 scan)
- One pixel per short (15bpp - Down to 1 scan)

daveythacher, 2025-03-29:
Set aside 128 bits for dot correction. Should it be 32 or 64 instead?

Accuracy:
- 128 bits 99.21875
- 64 bits 98.4375
- 32 bits 96.875
- 16 bits 93.75
- 8 bits 87.5

Note we do not need to consider hardware drift as we manage that too.
Note we can use integer math for this.

daveythacher, 2025-03-29:
Scrambled would use dot correction for minor. This allows multiplexing and additional colors to be dynamic.

daveythacher, 2025-03-29:
Can we support 32-scan panels? (Is the GCLK too high?)

daveythacher, 2025-04-17:
GEN 1: 8 colors max (1-bit per color)
GEN 2/3: Up to 4096 colors (1 scan), 512 (2 scan), 64 (4 scan) or 8 colors (8 and 16 scan). (Assuming 12-bits and 8-bits of dot.)

8-bits of dot correction means +/- 0.8% or 1.6% between channels.

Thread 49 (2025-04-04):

Write Concurrent::DMA independent of hardware

daveythacher, 2025-04-04:
Think about the problem not the solution.

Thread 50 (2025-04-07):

Add Concurrent::Atomic

daveythacher, 2025-04-07:

daveythacher, 2025-05-14:
This is no longer really required. Was required for multiple readers from a queue, aka a parent identity. Little concern exists for performance requiring two compute threads.

A mutex would have been capable of implementing the atomic function, but atomic is nicer. RP2040 does not have hardware for accelerating the performance of a mutex based implementation. Currently the expectation with the locks is in-order by both the processor and compiler. Not likely a safe assumption.

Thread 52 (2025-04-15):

Watchdog on FreeRTOS

daveythacher, 2025-04-15:
Lot of RTOS error cases possible. (Tasking isolation, task crashing, etc.) How to update watchdog, requires planning to insure correct functionality.

Correction function:
The function of a watchdog is to provide indirect detection of deviation from expectation. A watchdog will call an power event with an event notification as an error handler. This will correct the deviation, but not in a complete sense. (State may not be recovered between power events, for example.)

The function of a watchdog in fail safe, is detection and forced action. It is component of redundancy and voting, but does not provide either. We can achieve some polymorphic policy management at this level, but not as much as redundancy or voting would provide.

Currently only watchdog level fail safe is planned for this component.

Correct functionality:
If the update is called from the wrong place, we will not have the watchdog detection function monitoring the expectation.

To date we are stateless. However a communications protocol may allow for this to change. The amount of information stored on the device between contexts is minimal. Well defined behavior from power events is expected. (Such as blanked display.)

Closed 2025-07-09.

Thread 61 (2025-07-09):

Figure out solution to LED intensity variation

daveythacher, 2025-07-09:
LED brightness varies as a function of temperature, manufacturing and usage. Currently there is no automatic process for doing this without computer vision. It is possible for LEDs to do this on their own, however I do not have access to such LEDs. I can make something like them but those are cost prohibitive.

daveythacher, 2025-07-09:
Such digital signal processing would need to model multiple dimensions of intensity without direct measurement. Therefore neopixel is the preferred approach. (Direct measurement and compensation.)

* LED intensity can vary as a function of power rail/cable, LED driver ground pin and/or PCB traces/planes.
* LED intensity can vary as a function of LED temperature from previous refresh and/or frame.
* LED intensity can vary as a function of LED driver temperature from previous multiplex.
* LED intensity can vary as a function of manufacturing.

daveythacher, 2025-07-09:
Note neopixels should provide a means of error detection using a boundary scan based test approach. Thereby allowing them to fail to an observable error state by default. This requires multiple types of fault detection to prove operation of the control plane.

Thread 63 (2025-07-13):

Evaluate S-PWM performance

daveythacher, 2025-07-13:
Are high refresh rates along enough to compensate for LED intensity variation? If so, S-PWM with hardware PWM LED drivers may be a workable solution.

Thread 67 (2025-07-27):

Consider replacing PWM with BCM (BAM)

daveythacher, 2025-07-27:
Since we are only considering continuous operation (digital) instead of discontinuous operation (analog), we can use BCM (BAM) for at least the serial protocol. We can reorder BCM (BAM) onto PWM output using computation on device if desired. Keeping the underlying representation on device as PWM would help increase support for discontinuous operation. This can be achieved with memcpy or a special for loop routine.

The net result of this is higher serial through put for the same number of pixels. This would allow increasing the frame rate over the serial protocol. Potentially allowing up to the actual refresh rate of the device. This would allow removing the synchronization signals (GPIO flags) currently used by the serial protocol.

Note this is a moot point due to #61, which is a blocker. Also please consider this change will likely be replaced in the future by the work outlined in #61.

daveythacher, 2025-08-11:
This does not restrict #60.

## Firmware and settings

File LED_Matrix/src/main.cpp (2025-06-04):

/* 
 * File:   main.cpp
 * Author: David Thacher
 * License: GPL 3.0
 */

#include <new>
#include "Interface/Node/Node.h"
#include "Interface/Protocol/Protocol.h"
#include "Matrix/Matrix.h"
#include "System/Watchdog.h"

static void crash() {
    System::Watchdog::crash();
}

int main() {    
    std::set_new_handler(crash);
    System::Watchdog::enable(100);
    Interface::Protocol::Protocol::create_protocol(Interface::Node::Node::create_node())->work();
}

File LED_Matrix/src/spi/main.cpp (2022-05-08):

/* 
 * File:   main.cpp
 * Author: David Thacher
 * License: GPL 3.0
 */

extern void matrix_start();
extern void serial_start();
extern void isr_start();
extern void serial_task();

int main() {
    matrix_start();
    serial_start();
    isr_start();
    
    while (1) {
        serial_task();
    }
}

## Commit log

2023-03-10 #13 Removing PWM_bits from ON_OFF. Fixing issue found in PWM matrix algorithm. (Did not sent null line before multiplex.)
2023-04-12 Making PIO code better...I think I was tired when I wrote the first draft.
2023-05-27 #20 Updates: Serial Protocol changes to mark frames
2023-05-28 #7 Switching back to RGB-48 this limits panel size to 64x64 for GEN 3. TLC5958 is in theory capable of 64x128 see #7 for details. (LEDs only have 12 bits of color depth and multiplex lowers this.)
2023-05-30 Updating to use CRC in serial uart
2023-07-13 Make uart_getc non-blocking
2023-07-14 Fix real time bug. Pushing serial messages can create blocking logic which stalls multiplexing. If this was single core this could have resulted in infinite stall condition. This could have been fixe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
2023-07-14 Make main loop a ram function. Currently we use copy to RAM, but just in case I want to use defaul
2023-09-19 Add timer in place of blocking loop....not sure this is worth it.
2023-09-19 Add timer in place of blocking loop....not sure this is worth it. Yeah I did not test this either.
2023-11-29 Cleanup (#35)
    * Updates
    * Updates
    * updates
    * updates
    * Updates
    [Interface.brd, Interface.sch]
2023-12-04 If serial algorithm is faster than matrix algorithm drop the frame. This should not matter if the matrix algorithm's refresh rate is several times faster than serial algorithm's frame rate. Before th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
2023-12-18 Adding S-PWM algorithm to increase color depth for PWM algorithm
2023-12-20 Adding S-BCM which is a version of S-PWM. Instead of using PWM in the S-PWM segments it uses BCM, which saves memory.
2024-01-18 Updates. Note removed DMA checksum as this protocol expects a constant 30 FPS. Corruption on the wire should not create issues so long as framing is held constant. Note framing has not been added. Th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
2024-02-26 Nibble trick for mapping 6 16-bit values into 16 8-bit values. This does not really save memory but does reduce the number of PIO state machines required. This increases runtime complexity slightly. 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
2024-03-17 Revert "Updates"
    This reverts commit 97853e4421f73e8aa32ab6936821fa391e5939d6.
    [main.cpp]
2024-03-24 Removing worker thread. Worker logic kept for testing.
2024-03-27 Revert "Merge pull request #38 from daveythacher/loafer"
    This reverts commit ee1cb6a363d868b176e183150e1e11735db16e3d, reversing
    changes made to 1ebd4586b99a818c9bbd259b16e13a94d8b85f33.
    [main.cpp]
2024-08-20 Starting refactor of Node Serial UART
2024-08-20 Refactoring Node Serial UART
2024-10-27 Reducing load times. Not finished. Only worked on PWM algorithm. Still need to do BCM.
2024-11-03 Updates for BCM. Still both BCM and PWM are missing VSYNC function
2024-11-04 Help smooth out the access time. There is nothing we can do for DMA really. (Capacity vs arbiter size) We can possibly increase the CPU performance with block RAM.
2024-11-04 Clarify what has happened to DMA bandwidth and response time. Banking would potentially improve this, as multiplexing is a trap. This will lead to capacity loss.
2024-11-26 Holding back on RTOS for now. (Was considering a port to Teensy 4.) Still planning automation.
2024-12-03 Adding wrappers for DMA and PIO SM.
2024-12-07 Removing interrupts
2024-12-08 Switching to dynamic memory for the fun of it
2024-12-11 Serial is completely garbage. Still working on Matrix::Buffer and Matrix::Packet. Still working on templates. Still working on DMA, Multiplex, PIO::SM, Matrix::Multiplex, Matrix::Matrix::, Matrix::Wo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
2024-12-20 Adding PWM_Buffer
2024-12-20 Splitting DMA header into multiple files
2025-03-09 DMA as service under its own cluster
2025-03-11 Frame thing for out of order
2025-03-21 Syncing work in progress. Adding wrapper for PWM_Worker to allow different implementations. Dot product in some hardware configuration may be faster than LUTversion. For RP2040 LUT version is better.
2025-04-04 Adding dot product sample
2025-04-11 #49 Reworking headers for Concurrent::IO::DMA.
2025-04-11 Improve sleep time in Matrix/HUB75/PWM/PWM_Multiplex
2025-05-14 Removing templates and dynamic configuration from Matrix. Only going to support 8x8 matrix. Consider feature mode to enable channeling the monocolor via pin. Assuming tricolor matrix but only on colo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
2025-05-14 Saving copy of old PWM Worker LUT approach.
2025-05-14 Saving a copy of DMA and Frame approach.
2025-05-15 Switching status to embrace threads. Considering removing control notion and forcing host to implement hardware networking front end solution.
2025-05-20 Removing test modules. Removing mono module. Removing PWM_Worker
2025-05-20 Removing DMA wrappers. Using file based port layer. Removing Frame wrappers. Using file based port layer.
2025-05-20 Changing hardware profile to led the colors be decided by the hardware and the high level software. This code is just a universal intermediate which does not care. BUS8 is a new 8-bit bus design whic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
2025-05-29 Adding blob for SPWM frame, work in progress.
2025-06-02 Having processor flush before DMA operations.
2025-06-03 Adding Command header to allow for matrix data and frame swap.
2025-06-03 Adding Control command(s) and Power command for turning off LED array
2025-06-03 Getting the latest changes to LED Panel Settings Calculator Script
2025-06-03 Filling in filters. Making filter length programmable. No longer a power of 2 in length. RP2040 does not care but SIMD capable hardware probably would.
2025-06-04 Adding most of power command.
2025-06-04 Adding connection to power command and matrix implementation(s).
2025-06-07 Updating LED Panel Setting Calculator
2025-06-10 Adding reboot command. Adding logic for power command. Adding commands to TCAM.

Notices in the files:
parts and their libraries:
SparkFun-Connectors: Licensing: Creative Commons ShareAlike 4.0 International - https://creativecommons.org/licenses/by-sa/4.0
